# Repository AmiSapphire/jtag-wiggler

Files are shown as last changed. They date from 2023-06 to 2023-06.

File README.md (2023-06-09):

This project was originally for my own private personal use, but I am deciding to make this a repository anyway.

This is also my first time using vias on a PCB layout! Oh, this was made with KiCAD 7.0, so any earlier release will not work.

The circuit was tested with a 74HC244 IC and TJTAG 3.0.1 and 3.0.2.1 on a few machines with success barring issues with using one 74HC244; replacing it with another 74HC244 from the same set fixed the recognition issue. This is why a 74HCT244 is recommended with this circuit.

--

This same circuit on a perfboard - prototype unit before the final PCB design... photos aren't as clear; my long retired LG G7 ThinQ was better for this.
Also, the jumpers for switching 3V3/5V0 exist because I do not have a DPDT switch on hand.

Top view
IMG_20230608_184524307~2

Bottom view
IMG_20230608_221627281~2

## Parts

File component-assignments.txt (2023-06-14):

Layout - Component Assignments

--

JTAG Section

J1 - DSUB-25 Connector, Right Angle, Male [1]
P1 - 2 pin header
P2 - 3 pin header
P3 - 8 pin header
U1 - 74HCT244 octal buffer/line driver [2]
Q1 - 2N3904 transistor [3]
D1 - 5mm LED, Yellow (VREF power indicator)
C1 - Ceramic or Film cap, 100nf (output voltage filter)
R1 - 1/4W resistor, 10K (to 2N3904, base)
R2 - 1/4W resistor, 100 (to 74HCT244, 1A0)
R3 - 1/4W resistor, 100 (to 74HCT244, 1A1)
R4 - 1/4W resistor, 100 (to 74HCT244, 1A2)
R5 - 1/4W resistor, 100 (to 74HCT244, 1A3)
R6 - 1/4W resistor, 100 (from 74HCT244, 2Y0)
R7 - 1/4W resistor, 47K (to 2N3904, base to emitter ground)
R8 - 1/4W resistor, 2K2 (TMS power tap, current limiter)
R9 - 1/4W resistor, 2K2 (TCK power tap, current limiter)
R10 - 1/4W resistor, 2K2 (TDI power tap, current limiter)
R11 - 1/4W resistor, 2K2 (nTRST power tap, current limiter)
R12 - 1/4W resistor, 100 (from 2N3904, collector to nSRST)
R13 - 1/4W resistor, 100 (to 74HCT244, 2A0, TDO)
R14 - 1/4W resistor, 100 (from 74HCT244, 1Y3, nTRST)
R15 - 1/4W resistor, 100 (from 74HCT244, 1Y2, TDI)
R16 - 1/4W resistor, 100 (from 74HCT244, 1Y1, TCK)
R17 - 1/4W resistor, 100 (from 74HCT244, 1Y0, TMS)
R18 - 1/4W resistor, 1K (nSRST pullup resistor)
R19 - 1/4W resistor, 330 to 5K1 (VREF LED current limiter) [4]

Dual Power Supply Section

J2 - Barrel Jack, 5.5mm x 2.1mm, female, 3 prong (VCC)
SW1 - Sub-miniature DPDT ON-ON switch, 2.54mm x 5.08mm pin spacing (3V3/5V0
  power switch)
U2 - LM1117T-ADJ or LD1117 LDO regulator (3V3 power supply)
U3 - LM1117T-ADJ or LD1117 LDO regulator (5V0 power supply)
D2 - 5mm LED, Green (3V3 power indicator)
D3 - 5mm LED, Red (5V0 power indicator)
D4 - DO-41 diode, 1N4004 to 1N4007 (protection diode)
C2 - Electrolytic cap, 100uf 16V (3V3 power supply in filter)
C3 - Electrolytic cap, 100uf 6.3V (3V3 power supply adj to out filter)
C4 - Electrolytic cap, 100uf 6.3V (3V3 power supply out filter)
C5 - Electrolytic cap, 100uf 16V (5V0 power supply in filter)
C6 - Electrolytic cap, 100uf 6.3V (5V0 power supply adj to out filter)
C7 - Electrolytic cap, 100uf 6.3V (5V0 power supply out filter)
R20 - 1/4W resistor, 330 (3V3 power supply adj)
R21 - 1/4W resistor, 200 (3V3 power supply out)
R22 - 1/4W resistor, 330 to 5K1 (3V3 LED current limiter) [4]
R23 - 1/4W resistor, 680 (5V0 power supply adj)
R24 - 1/4W resistor, 220 (5V0 power supply out)
R25 - 1/4W resistor, 330 to 5K1 (5V0 LED current limiter) [4]

Notes

[1] The US standard is preferred, as this board is designed in the US. The
    European standard may fit, but the installation may be off by ~1.3mm; it
    will slightly stick out. For the European standard, please use the
    jtag-wiggler_euro PCB.

    US standard
    board edge to nearest pin line: ~8.08mm
    board edge to mounting hole: ~9.50mm
    
    European standard
    board edge to nearest pin line: ~9.40mm
    board edge to mounting pin: ~11.80mm

[2] You can also use the HC variant, but HCT is recommended. You're also better
    off socketing this IC!

[3] 2N3904 NPN transistor is from the original alec @ sensi.org schematic. It
    is US-centric, however. The onetransistor.eu schematic uses the BC548 due
    to the schematic's European origin. To install the BC548 NPN transistor, it
    must be installed backward in comparison to its 2N3904 cousin.

    However, the other European BC547 is exactly pin-to-pin compatible to the
    2N3904, so backwards installation is not necessary.

    2N3904, 2N2222, BC547 = EBC
    BC548, BC337 = CBE

[4] LED brightness. The higher value the resistor is, the lower the LED's
    brightness is. Notice R20 is separate from these resistors. Do NOT change
    this particular resistor unless you know what you are doing, as it affects
    the set voltage from 3V3!

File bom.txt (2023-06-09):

Parallel JTAG (Wiggler) - BOM

--

Capacitors

(1) ceramic or film cap, 100nf
(2) electrolytic cap, 100uf 16V
(4) electrolytic cap, 100uf 6.3V

Resistors

(11) 1/4W resistor, 100
(1) 1/4W resistor, 200
(1) 1/4W resistor, 220
(1) 1/4W resistor, 330
(3) 1/4W resistor, 330 to 5K1
(1) 1/4W resistor, 680
(1) 1/4W resistor, 1K
(4) 1/4W resistor, 2K2
(1) 1/4W resistor, 10K
(1) 1/4W resistor, 47K

LEDs

(1) 5mm LED, Red
(1) 5mm LED, Yellow
(1) 5mm LED, Green

Headers

(1) 2 pin header
(1) 3 pin header
(1) 8 pin header

Other Components

(1) DSUB-25 connector, right angle, male
(1) 74HCT244 octal buffer/line driver
(1) 20-pin socket [recommended]
(1) 2N3904 transistor
(1) DO-41 diode, 1N4004 to 1N4007
(1) barrel jack, 5.5mm x 2.1mm, female, 3 prong
(1) Sub-miniature DPDT ON-ON switch, 2.54mm x 5.08mm pin spacing
(2) LM1117T-ADJ or LD1117 LDO regulator

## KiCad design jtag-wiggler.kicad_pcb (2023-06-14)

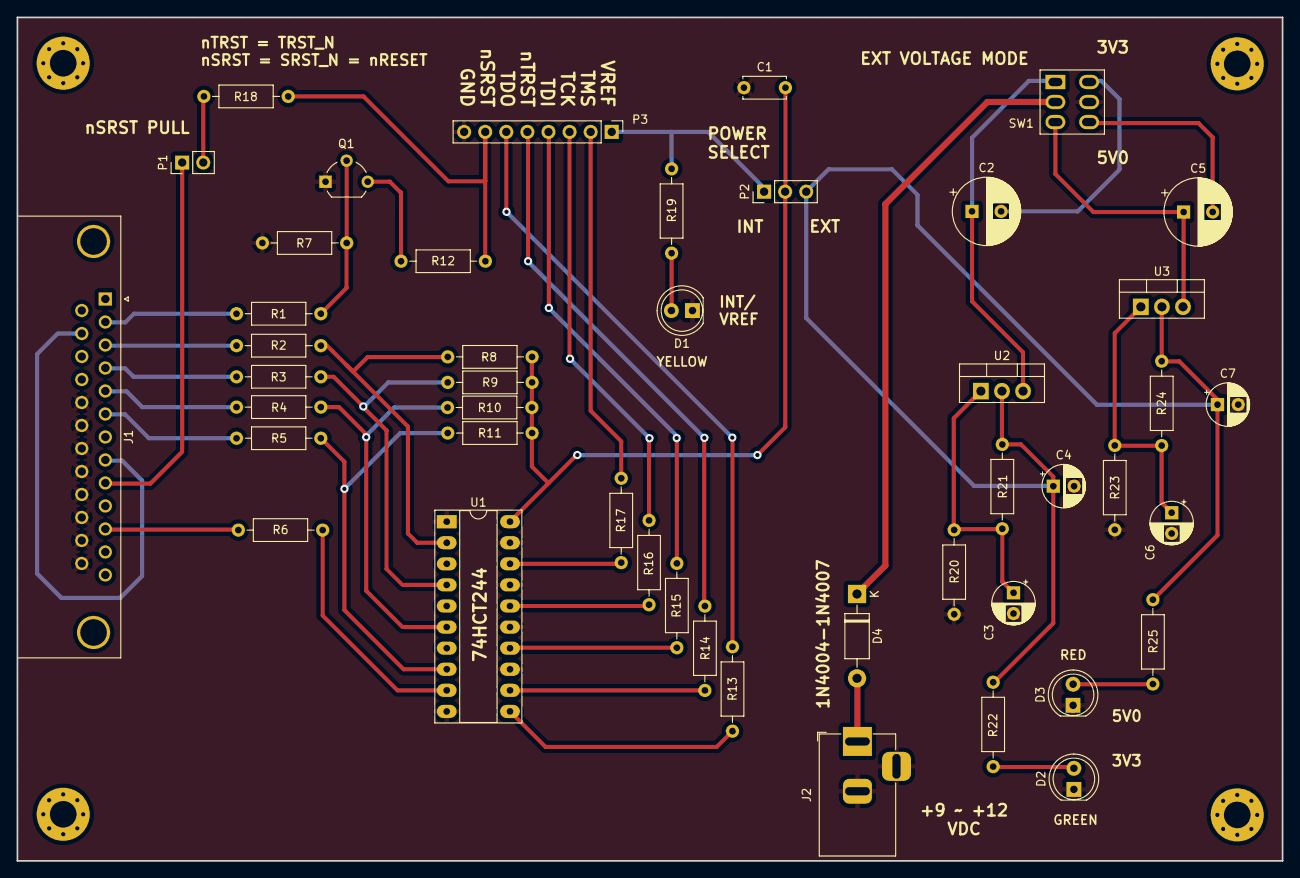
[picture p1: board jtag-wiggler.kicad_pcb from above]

Board: 2 copper layers, 152.4 x 101.6 mm, 50 parts (0 on the bottom side), 42 nets.

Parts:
C1: C_Disc_D5.0mm_W2.5mm_P5.00mm
C2, C5: CP_Radial_D8.0mm_P3.50mm
C3, C4, C6, C7: CP_Radial_D5.0mm_P2.50mm
D1, D2, D3: LED_D5.0mm
D4: D_DO-41_SOD81_P10.16mm_Horizontal
J1: DSUB-25_Male_Horizontal_P2.77x2.84mm_EdgePinOffse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; DSUB-25_Male_Horizontal_P2.77x2.84mm_EdgePinOffset7.70mm_Ho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
J2: BarrelJack_Horizontal
P1: PinHeader_1x02_P2.54mm_Vertical
P2: PinHeader_1x03_P2.54mm_Vertical
P3: PinHeader_1x08_P2.54mm_Vertical
Q1: TO-92_Wide
R1, R2, R3, R4, R5, R6, R7, R8, R9, R10, R11, R12, R13, R14, R15, R16, R17, R18, R19, R20, R21, R22, R23, R24, R25: R_Axial_DIN0207_L6.3mm_D2.5mm_P10.16mm_Horizontal
SW1: SW_Generic
U1: DIP-20_W7.62mm_Socket_LongPads
U2, U3: TO-220-3_Vertical
X1, X2, X3, X4: MountingHole_3.2mm_M3_Pad_Via

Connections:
/PSU_In: C4.1, C7.1, P2.3, R21.1, R22.1, R24.1, R25.1, U2.2, U3.2
/PWR_SELECT: C1.2, P2.2, R8.1, R9.1, R10.1, R11.1, U1.20
BUSY: J1.11, R6.1
C2_negative: C2.2, SW1.6
C2_positive: C2.1, SW1.1, U2.3
C5_negative: C5.2, SW1.4
C5_positive: C5.1, SW1.3, U3.3
D1: J1.2, R1.1
D2: J1.3, R2.1
D3: J1.4, R3.1
D4: J1.5, R4.1
D5: J1.6, R5.1
ERROR: J1.8, J1.15
GND: C1.1, C3.2, C4.2, C6.2, C7.2, D1.1, D2.1, D3.1, J1.18, J1.19, J1.20, J1.21, J1.22, J1.23, J1.24, J1.25, J2.2, J2.3, P3.8, Q1.1, R7.2, R20.2, R23.2, SW1.5, U1.1, U1.10, U1.13, U1.15, U1.17, U1.19
unnamed: D1.2, R19.1
unnamed: D2.2, R22.2
unnamed: D3.2, R25.2
unnamed: P1.2, R18.2
unnamed: Q1.2, R1.2, R7.1
unnamed: Q1.3, R12.1
unnamed: R2.2, R8.2, U1.2
unnamed: R3.2, R9.2, U1.4
unnamed: R4.2, R10.2, U1.6
unnamed: R5.2, R11.2, U1.8
unnamed: R17.1, U1.18
unnamed: R16.1, U1.16
unnamed: R15.1, U1.14
unnamed: R14.1, U1.12
unnamed: R13.1, U1.11
unnamed: R6.2, U1.9
unnamed: C3.1, R20.1, R21.2, U2.1
unnamed: C6.1, R23.1, R24.2, U3.1
PC_VCC: J1.9, P1.1
Protected_VCC: D4.1, SW1.2
TCK: P3.3, R16.2
TDI: P3.4, R15.2
TDO: P3.6, R13.2
TMS: P3.2, R17.2
VCC: D4.2, J2.1
VREF: P2.1, P3.1, R19.2
nSRST: P3.7, R12.2, R18.1
nTRST: P3.5, R14.2

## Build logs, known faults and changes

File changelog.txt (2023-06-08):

Changelog
These were formerly in the schematic and PCB files as comments.

---

Schematic - Main JTAG Section

2023/05/31 - Original Revision
2023/06/02 - Revision 1.1: Fixes schematic parity with PCB
2023/06/03 - Revision 1.2: Identify wires with global labels (affects PCB design)
2023/06/04 - Revision 1.3: R14-R17 consistency change with PCB layout
2023/06/06 - Revision 1.4: 74HCT244 symbol tied to specific project for publication - schematic finalized!

Schematic - Dual Power Supply Section

2023/05/31 - Original Revision
2023/06/02 - Revision 1.1: Fixes voltage pinouts on DPDT switch
             Fixes schenatic parity with PCB
2023/06/04 - Revision 1.2: General cleanup - schematic finalized!

PCB - Complete Layout

2023/06/02 - Original Revision
2023/06/03 - Revision 1.1: Easy-to-read PCB nets and general cleanup (this required schematic changes)
2023/06/04 - Revision 1.2: Routing cleanup and Schematic credits
2023/06/04 - Revision 1.3: Major routing change regarding the barrel jack - potential
                             safety issue due to the JTAG header being near the power jack
                           Labeling of certain functions
                           Even more routing and general cleanup
                           Via size change
2023/06/05 - Revision 1.4: Implemented mounting holes
                           Slightly reworded schematic credits
                           Text labeling consistency changes
2023/06/06 - Revision 1.5: Change diode footprint
                           Add diode series range
                           Change design check preferences - board finalized!

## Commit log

2023-06-09 Update README.md
    Add top view of prototype circuit design. Remind self to take a photo of the bottom view later.
2023-06-09 Update README.md
    Previous commit also fixes TJTAG version typo. Current commit adds a bottom view photo and adds some detail regarding the jumpers on the prototype circuit.
2023-06-09 Add custom switch footprint; update PCB layout
    [jtag-wiggler.kicad_pcb]
2023-06-09 Update BOM to specify switch pin spacing
2023-06-09 Specify SW1 as 'Sub-miniature DPDT switch'
2023-06-09 Update SW1 footprint; fits up to 1.5mm pin width
    [jtag-wiggler.kicad_pcb]
2023-06-09 Specify KiCAD ver., because this is important
2023-06-12 Change SW1 footprint to 1.0mm vertical
    [jtag-wiggler.kicad_pcb]
2023-06-14 Remove extra track from D2; general PCB cleanup
    [jtag-wiggler.kicad_pcb]
2023-06-14 Add European standard PCB and reference
    [jtag-wiggler_euro.kicad_pcb]
2023-06-14 Rev number bump, add comment for US/Euro Standard
    [jtag-wiggler.kicad_pcb, jtag-wiggler_euro.kicad_pcb]
